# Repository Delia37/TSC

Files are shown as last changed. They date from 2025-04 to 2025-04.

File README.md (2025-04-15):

# EBookReader

Am inceput implementarea proiectului pornind de la schema electrica data in enunt. Am luat pe rand componentele din biblioteca pusa la dispozitie, apoi le-am conctat si le-am pus label-urile. Am verificat cu ERC si am rezolvat erorile, majoritatea fiind de la pini suprapusi sau etichete puse prost. Am ramas cu o eroare pe care nu am putut sa o rezolv, deoarece Fusion nu i-a detectat locatia. Odata terminata schema electrica, am facut trecut la implementarea pcb-ului. Am decupat forma dupa dimensiunile cerute si am masurat laturile. Dificultatea cea mai mare de la acest pas a constat in identificarea pieselor. Dupa amplasarea lor, am rutat si am verificat cu regulile date in enunt. Aici a fost nevoie sa modific footprint-ul bobinei L1 pentru a nu mai avea erori. La final, am facut si planul de masa atat pe top, cat si pe bottom.

---

## Arhitectură Generală a Sistemului

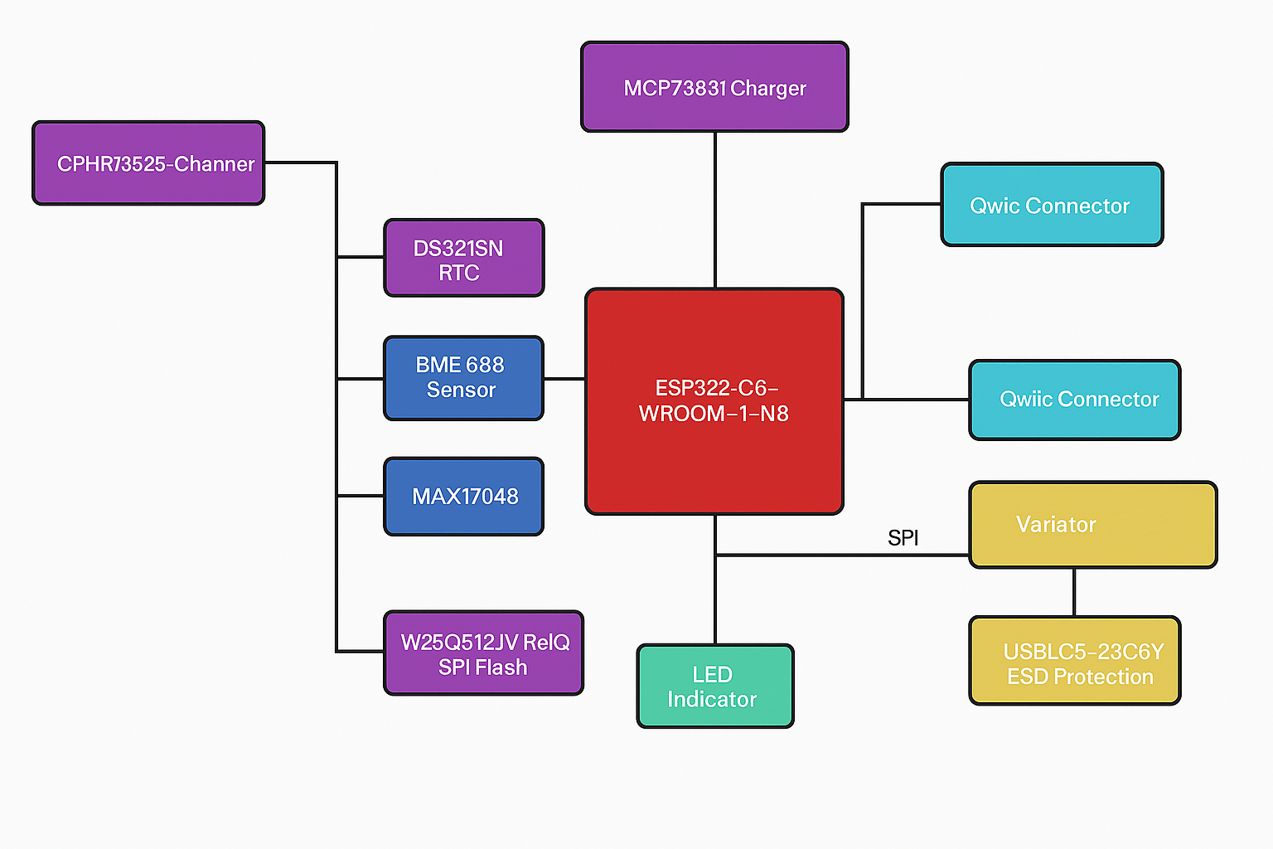
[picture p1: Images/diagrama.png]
Diagrama Bloc


ESP32-C6-WROOM-1-N8 acționează ca nod central, comunicând cu toate celelalte componente prin interfețe standard (I2C, SPI, GPIO). Alimentarea este asigurată de o baterie Li-Po controlată de un încărcător dedicat și monitorizată printr-un fuel gauge.

---

## Detalii Hardware

### ESP32-C6
- Procesor RISC-V cu conectivitate Wi-Fi 6 & BLE
- Comunicare: SPI, I2C, GPIO, UART
- Tensiune operare: 3.3V

### Management Energie
- MCP73831 – control încărcare baterie LiPo
- MAX17048 – monitorizare nivel baterie cu semnal alertă
- XC6220A331MR – stabilizare la 3.3V

### Senzori și RTC
- BME688 – monitorizare temperatură, umiditate, presiune, VOC (I2C)
- DS3231SN – ceas de timp real cu alarmă (I2C)

### Display și Stocare
- E-paper display – consum redus, ideal pentru afișaj static
- W25Q512JVEIQ – memorie NOR SPI externă, 64Mbit
- SD Card – opțional, conectat prin SPI partajat

### Protecție și Conectivitate
- Protecție ESD pe linii USB (USBLC6)
- Diode Schottky pentru protecție la supratensiune
- Port USB-C pentru alimentare și comunicație serială

### Interfețe Utilizator
- Buton RESET
- LED pentru starea încărcării

---

## Bill of Materials (CSV)

Fișierul complet BOM este disponibil aici: [Manufacturing/bom.csv](../Manufacturing/bom.csv)

---

## Alocare Pini ESP32-C6

| Componentă | Pin ESP32 | Funcție |
|---|---|---|
| BME688 – SDA | IO8 | I2C SDA |
| BME688 – SCL | IO9 | I2C SCL |
| DS3231SN – INT | IO10 | Interrupt RTC  |
| W25Q512 – CS | IO4 | SPI Flash CS |
| E-Paper – CS | IO3 | SPI Display CS |
| SPI – CLK | IO5 | SPI Clock |
| SPI – MOSI | IO6 | SPI MOSI |
| SPI – MISO | IO7 | SPI MISO |
| MAX17048 – ALERT | IO11 | Fuel Gauge INT |
| Buton RESET | IO0 | Boot/Reset |
| SD Card – CS | IO2 | SPI CS SD Card |

---
## Imagini Asamblare și PCB

### Randare 3D
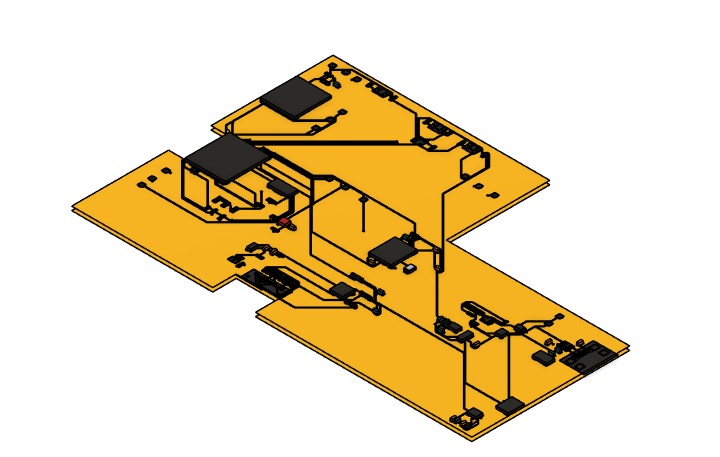
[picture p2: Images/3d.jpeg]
Randare 3D


### PCB - Top Layer
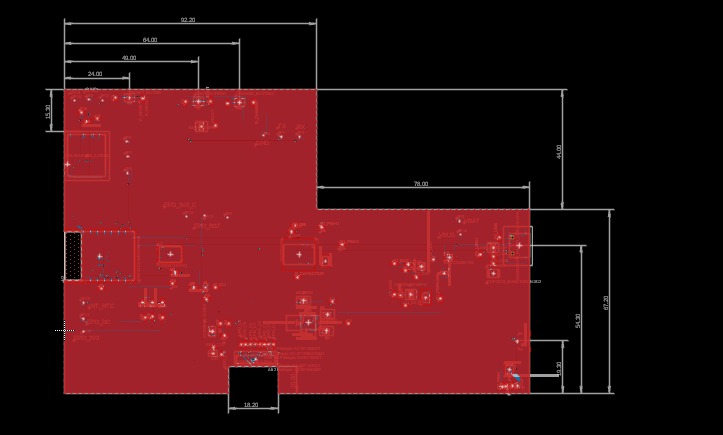
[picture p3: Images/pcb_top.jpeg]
PCB Top


### PCB - Bottom Layer
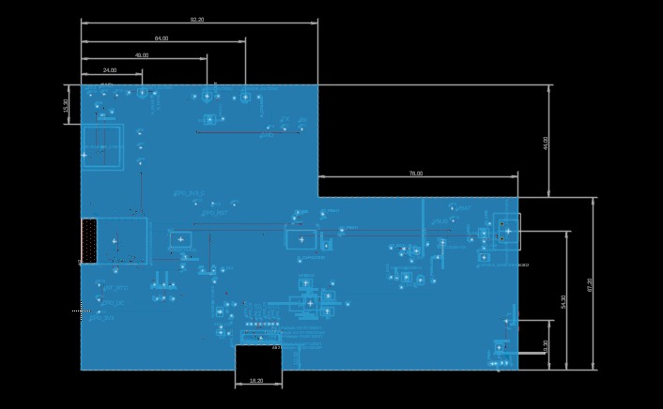
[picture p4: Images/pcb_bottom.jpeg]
PCB Bottom


---

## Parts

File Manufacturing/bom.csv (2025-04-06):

Qty | Value | Device | Package | Parts | Description | ARROW_PART_NUMBER | ARROW_PRICE-STOCK | AVAILABILITY | CENTROID_NOT_SPECIFIED | CHECK_PRICES | COPYRIGHT | DATASHEET | DESCRIPTION | DIGIKEY_DESCRIPTION | DIGIKEY_PART_NUMBER | HEIGHT | LEAD_FREE | MANUFACTURER_NAME | MANUFACTURER_PART_NUMBER | MF | MFR_NAME | MOUSER_PART_NUMBER | MOUSER_PRICE-STOCK | MOUSER_TESTING_PART_NUMBER | MOUSER_TESTING_PRICE-STOCK | MP | MPN | PACKAGE | POPULARITY | PREFIX | PRICE | PROD_ID | PURCHASE-URL | ROHS | SNAPEDA_LINK | SPICEMODEL | SPICEPREFIX | TEMPERATURE_RANGE_HIGH | TEMPERATURE_RANGE_LOW | TP_SIGNAL_NAME | VALUE
1 |  | ADAFRUIT_LEDCHIP-LED0603 | ADAFRUIT_CHIP-LED0603 | CHG_LED | LED
1 |  | SJ | SJ | SJ1 | SMD solder JUMPER |  |  |  |  |  |  |  |  |  |  |  |  |  |  |  |  |  |  |  |  |  |  |  | 3
8 | 0.1uF/50V | ESP32_WROVER_EAGLE-LTSPICE_CC0402 | ESP32_WROVER_EAGLE-LTSPICE_C0402 | EPD_C5, EPD_C6, EPD_C7, EPD_C8, EPD_C9, EPD_C10, EPD_C11, EPD_C12 | CAPACITOR, European symbol |  |  |  |  |  |  |  |  |  |  |  |  |  |  |  |  |  |  |  |  |  |  |  |  |  |  |  |  |  |  | NONE | C
1 | 0.47 | ESP32_WROVER_EAGLE-LTSPICE_RR0402 | ESP32_WROVER_EAGLE-LTSPICE_R0402 | R3 | RESISTOR, European symbol |  |  |  |  |  |  |  |  |  |  |  |  |  |  |  |  |  |  |  |  |  |  |  |  |  |  |  |  |  |  | NONE | R
1 | 100K | ESP32_WROVER_EAGLE-LTSPICE_RR0402 | ESP32_WROVER_EAGLE-LTSPICE_R0402 | R1_PWRUSB | RESISTOR, European symbol
6 | 100nF | ESP32_WROVER_EAGLE-LTSPICE_CC0402 | ESP32_WROVER_EAGLE-LTSPICE_C0402 | C1, C2, C4_USB, C7, C8, C_DELAY | CAPACITOR, European symbol |  |  |  |  |  |  |  |  |  |  |  |  |  |  |  |  |  |  |  |  |  |  |  |  |  |  |  |  |  |  | NONE | C
1 | 100uF TANT | RCL_CPOL-EUCT3528 | RCL_CT3528 | C11 | POLARIZED CAPACITOR, European symbol |  |  |  |  |  |  |  |  |  |  |  |  |  |  |  |  |  |  |  |  |  |  |  | 0 |  |  |  |  |  |  |  | C
13 | 10K | ESP32_WROVER_EAGLE-LTSPICE_RR0402 | ESP32_WROVER_EAGLE-LTSPICE_R0402 | R1_PINH, R1_PINH1, R2-PINH, R2-PINH1, R5, R6, R7, R8, R9, R10, R_BOOT, R_CHANGE, R_RESET | RESISTOR, European symbol
2 | 10k | ESP32_WROVER_EAGLE-LTSPICE_RR0402 | ESP32_WROVER_EAGLE-LTSPICE_R0402 | R1, R_CL1 | RESISTOR, European symbol
1 | 10k | ESP32_WROVER_EAGLE-LTSPICE_RR0402 | ESP32_WROVER_EAGLE-LTSPICE_R0402 | R4 | RESISTOR, European symbol |  |  |  |  |  |  |  |  |  |  |  |  |  |  |  |  |  |  |  |  |  |  |  |  |  |  |  |  |  |  | NONE | R
4 | 10uF | ESP32_WROVER_EAGLE-LTSPICE_CC0402 | ESP32_WROVER_EAGLE-LTSPICE_C0402 | C3, C5, C6, C10 | CAPACITOR, European symbol |  |  |  |  |  |  |  |  |  |  |  |  |  |  |  |  |  |  |  |  |  |  |  |  |  |  |  |  |  |  | NONE | C
1 | 112A-TAAR-R03_ATTEND | 112A-TAAR-R03_ATTEND | 112ATAARR03ATTEND | J4 | Micro SD Card Socket, Push-Push Type, Top Mount, SMT, H=1.83mm, 10u |  |  |  |  |  |  |  | Micro SD Card Socket | Push-Push Type | Top Mount | SMT | H=1.83mm | 10u |  |  | 1.9mm |  | ATTEND | 112A-TAAR-R03 ATTEND
1 | 15 | ESP32_WROVER_EAGLE-LTSPICE_RR0402 | ESP32_WROVER_EAGLE-LTSPICE_R0402 | R_CAPACITOR | RESISTOR, European symbol
2 | 1uF/50V | ESP32_WROVER_EAGLE-LTSPICE_CC0402 | ESP32_WROVER_EAGLE-LTSPICE_C0402 | EPD_C1, EPD_C2 | CAPACITOR, European symbol |  |  |  |  |  |  |  |  |  |  |  |  |  |  |  |  |  |  |  |  |  |  |  |  |  |  |  |  |  |  | NONE | C
1 | 2.2 | ESP32_WROVER_EAGLE-LTSPICE_RR0402 | ESP32_WROVER_EAGLE-LTSPICE_R0402 | R2 | RESISTOR, European symbol
1 | 200 | ESP32_WROVER_EAGLE-LTSPICE_RR0402 | ESP32_WROVER_EAGLE-LTSPICE_R0402 | R1_BAT | RESISTOR, European symbol
2 | 20V/4.2A/52mO/1.4W | ESP32_WROVER_SPARKFUN-DISCRETESEMI_MOSFET_PCH-DMG2305UX-7 | ESP32_WROVER_SPARKFUN-DISCRETESEMI_SOT23-3 | Q2, Q3 | P-channel MOSFETs |  |  |  |  |  |  |  |  |  |  |  |  |  |  |  |  |  |  |  |  |  |  |  |  |  |  | TRAN-14388 |  |  |  |  |  |  |  |  | 20V/4.2A/52mO/1.4W
1 | 2k | ESP32_WROVER_EAGLE-LTSPICE_RR0402 | ESP32_WROVER_EAGLE-LTSPICE_R0402 | R2_BAT | RESISTOR, European symbol
5 | 4.7uF | ESP32_WROVER_EAGLE-LTSPICE_CC0402 | ESP32_WROVER_EAGLE-LTSPICE_C0402 | C1_BAT, C1_BAT1, C1_BAT2, C2_BAT, C5_USB | CAPACITOR, European symbol |  |  |  |  |  |  |  |  |  |  |  |  |  |  |  |  |  |  |  |  |  |  |  |  |  |  |  |  |  |  | NONE | C
1 | 4.7uF/25V | ESP32_WROVER_EAGLE-LTSPICE_CC0402 | ESP32_WROVER_EAGLE-LTSPICE_C0402 | C4 | CAPACITOR, European symbol |  |  |  |  |  |  |  |  |  |  |  |  |  |  |  |  |  |  |  |  |  |  |  |  |  |  |  |  |  |  | NONE | C
1 | 5K1 | ESP32_WROVER_EAGLE-LTSPICE_RR0402 | ESP32_WROVER_EAGLE-LTSPICE_R0402 | R2-USB1 | RESISTOR, European symbol
1 | 5k1 | ESP32_WROVER_EAGLE-LTSPICE_RR0402 | ESP32_WROVER_EAGLE-LTSPICE_R0402 | R2-USB | RESISTOR, European symbol
1 | 68uH | 744043680IND_4828-WE-TPC_WRE | IND_4828-WE-TPC_WRE | L1 |  |  |  |  |  |  | Copyright (C) 2024 Ultra Librarian. All rights reserved. |  |  |  |  |  |  |  | 744043680 |  | Wurth Electronics
1 | BD5229G-TR | BD5229G-TR | SOT95P280X125-5N | IC1 | Voltage Detector with Adjustable Delay Time: CMOS processes are utilized to develop high precision, low current consumption CMOS reset ICs that allow arbitrary setting of the delay time. The extensive lineup includes both Nch Open Drain and CMOS output types in a wide range of detection voltages (from 2.3V to 6.0V, in 0.1V steps), enabling selection of the ideal solution based on customer requirements. In addition, the entire series is of course both lead-free and RoHS-compliant. |  |  |  |  |  |  |  | Voltage Detector with Adjustable Delay Time: CMOS processes are utilized to develop high precision | low current consumption CMOS reset ICs that allow arbitrary setting of the delay time. The extensive lineup includes both Nch Open Drain and CMOS output types in a wide range of detection voltages (from 2.3V to 6.0V | in 0.1V steps) | enabling selection of the ideal solution based on customer requirements. In addition | the entire series is of course both lead-free and RoHS-compliant. |  |  | 1.25mm |  | ROHM Semiconductor | BD5229G-TR |  |  | 755-BD5229G-TR | https://www.mouser.co.uk/ProductDetail/ROHM-Semiconductor/BD5229G-TR?qs=4kLU8WoGk0vvnhrrYwdszw%3D%3D
3 | BUTTON_CUSYOMV1 | BUTTON_CUSYOMV1 | MYBUTTON | BOOT_BUTTON, CHANGE_BUTTON, RESET_BUTTON
1 | CPH3225A | CPH3225A | CAPCP3225X100N | C10_SUPERCAP | Cap 0.011F 3.3V 1210 Flat Check availability |  |  | Not in stock |  | https://www.snapeda.com/parts/CPH3225A/Seiko+Instruments/view-part/?ref=eda |  |  | 11 mF (EDLC) Supercapacitor 3.3 V 1210 (3225 Metric) - - |  |  |  |  |  |  | Seiko Instruments |  |  |  |  |  | CPH3225A |  | 1210 Seiko |  |  | None |  | https://www.snapeda.com/api/url_track_click_mouser/?unipart_id=562593&manufacturer=Seiko Instruments&part_name=CPH3225A&search_term=None |  | https://www.snapeda.com/parts/CPH3225A/Seiko+Instruments/view-part/?ref=snap
1 | DS3231SN# | DS3231SN# | SOIC127P1032X265-16N | U3 | Real Time Clock Serial 16-Pin SOIC W T/R Check availability |  |  | In Stock |  | https://www.snapeda.com/parts/DS3231SN%23/Analog+Devices/view-part/?ref=eda |  |  | Extremely Accurate I²C-Integrated RTC/TCXO/Crystal |  |  |  |  |  |  | Analog Devices |  |  |  |  |  | DS3231SN# |  | SOIC-16 Maxim |  |  | None |  | https://www.snapeda.com/api/url_track_click_mouser/?unipart_id=99048&manufacturer=Analog Devices&part_name=DS3231SN#&search_term=None |  | https://www.snapeda.com/parts/DS3231SN%23/Analog+Devices/view-part/?ref=snap
1 | ESP32-C6-WROOM-1-N8 | ESP32-C6-WROOM-1-N8 | XCVR_ESP32-C6-WROOM-1-N8 | U2 | Check availability |  |  | In Stock |  | https://www.snapeda.com/parts/ESP32-C6-WROOM-1-N8/Espressif+Systems/view-part/?ref=eda |  |  | Multiprotocol Modules ESP32-C6 module | Wi-Fi 6 in 2.4 GHz band | Bluetooth 5 | Zigbee 3.0 and Thread. ESP34-WROOM Compatible - ENGINEERING SAMPLE |  |  |  |  |  |  | Espressif Systems |  |  |  |  |  | ESP32-C6-WROOM-1-N8 |  | None |  |  | None |  |  |  | https://www.snapeda.com/parts/ESP32-C6-WROOM-1-N8/Espressif+Systems/view-part/?ref=snap
1 | ESP32C6_VARISTORCN1812 | ESP32C6_VARISTORCN1812 | ESP32C6_VARISTOR_CT/CN1812 | PFMF.050.1 | VARISTOR |  |  |  |  |  |  |  |  |  |  |  |  |  |  |  |  |  |  |  |  |  |  |  | 0
2 | ESP32_WROVER_AVX---SD0805S020S1R0_AVX_SD0805S020S1R0_0_0AVX_SD0805S020S1R0_0_0 | ESP32_WROVER_AVX---SD0805S020S1R0_AVX_SD0805S020S1R0_0_0AVX_SD0805S020S1R0_0_0 | ESP32_WROVER_AVX---SD0805S020S1R0_AVX_SD0805S020S1R0_0 | D2, D7 | Schottky Barrier Rectifier Diode |  |  |  | No |  |  | http://datasheets.avx.com/schottky.pdf |  | DIODE SCHOTTKY 20V 1A 0805 | 478-7800-1-ND |  | yes |  |  | AVX |  | 581-SD0805S020S1R0 |  |  |  |  |  | 0805 (2012 metric) |  | D |  |  |  | yes |  |  |  | +125°C | -55°C
1 | ESP32_WROVER_BME680_BME680 | ESP32_WROVER_BME680_BME680 | ESP32_WROVER_BME680_PSON80P300X300X100-8N | SENSOR2 | Integrated Environmental Unit |  |  | Unavailable |  |  |  |  | Integrated Environmental Unit |  |  |  |  |  |  | Bosch Sensortec |  |  |  |  |  | BME680 |  | LGA-8 Bosch Tools |  |  | None
1 | ESP32_WROVER_SPARKFUN-IC-POWER_MCP73831 | ESP32_WROVER_SPARKFUN-IC-POWER_MCP73831 | ESP32_WROVER_SPARKFUN-IC-POWER_SOT23-5 | MCP73831 | MCP73831T Li-Ion, Li-Pol Controller |  |  |  |  |  |  |  |  |  |  |  |  |  |  |  |  |  |  |  |  |  |  |  |  |  |  | IC-09995
1 | FH34SRJ-24S-0.5SH_99_ | FH34SRJ-24S-0.5SH_99_ | FH34SRJ24S05SH99 | J1 | (0.50mm) Surface Mount, Right Angle |  |  |  |  |  |  |  | 24 Position FFC | FPC Connector Contacts | (0.50mm) Surface Mount | Right Angle |  |  | 1.1mm |  | Hirose | FH34SRJ-24S-0.5SH(99) |  |  | 798-FH34SRJ24S05SH99 | https://www.mouser.co.uk/ProductDetail/Hirose-Connector/FH34SRJ-24S-0.5SH99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
1 | MAX17048G+T10 | MAX17048G+T10 | SON50P200X200X80-9N | U4 | Check availability |  |  | In Stock |  | https://www.snapeda.com/parts/MAX17048G+T10/Analog+Devices/view-part/?ref=eda |  |  | 3µA 1-Cell/2-Cell Fuel Gauge with ModelGauge |  |  |  |  |  |  | Analog Devices |  |  |  |  |  | MAX17048G+T10 |  | TDFN-8 Maxim |  |  | None |  | https://www.snapeda.com/api/url_track_click_mouser/?unipart_id=329239&manufacturer=Analog Devices&part_name=MAX17048G+T10&search_term=None |  | https://www.snapeda.com/parts/MAX17048G+T10/Analog+Devices/view-part/?ref=snap
3 | MBR0530 | MBR0530 | SOD3716X135N | D3, D4, D5 | ON SEMICONDUCTOR - MBR0530 - DIODE, SCHOTTKY, 0.5A, 30V, SOD-123 |  |  | In Stock |  | https://www.snapeda.com/parts/MBR0530/Onsemi/view-part/?ref=eda |  |  | Diode Schottky 30 V 500mA Surface Mount SOD-123 |  |  |  |  |  |  | ON Semiconductor |  |  |  |  |  | MBR0530 |  | SOD-123-2 ON Semiconductor |  |  | None |  | https://www.snapeda.com/api/url_track_click_mouser/?unipart_id=179458&manufacturer=ON Semiconductor&part_name=MBR0530&search_term=None |  | https://www.snapeda.com/parts/MBR0530/Onsemi/view-part/?ref=snap
6 | PGB1010603MR | PGB1010603MR | DIOC1608X36N | D6, D8, D9, D10, D11, D12 | Check availability |  |  | In Stock |  | https://www.snapeda.com/parts/PGB1010603MR/Littelfuse/view-part/?ref=eda |  |  | 150V (Typ) Clamp - Ipp Tvs Diode Surface Mount 0603 (1608 Metric) |  |  |  |  |  |  | Littelfuse Inc. |  |  |  |  |  | PGB1010603MR |  | 0603 Littelfuse Inc. |  |  | None |  | https://www.snapeda.com/api/url_track_click_mouser/?unipart_id=5659453&manufacturer=Littelfuse Inc.&part_name=PGB1010603MR&search_term=None |  | https://www.snapeda.com/parts/PGB1010603MR/Littelfuse/view-part/?ref=snap
1 | QWIIC_RIGHT_ANGLE | QWIIC_CONNECTORJS-1MM | JST04_1MM_RA | J3 | SparkFun I2C Standard Qwiic Connector |  |  |  |  |  |  |  |  |  |  |  |  |  |  |  |  |  |  |  |  |  |  |  |  |  |  | CONN-13694 |  |  |  |  |  |  |  |  | QWIIC_RIGHT_ANGLE
1 | SAMACSYS_PARTS_USB4110-GF-A | SAMACSYS_PARTS_USB4110-GF-A | SAMACSYS_PARTS_USB4110GFA | J2 | CONN USB 2.0 TYPE-C R/A SMT |  |  |  |  |  |  |  | CONN USB 2.0 TYPE-C R/A SMT |  |  | 3.26mm |  | GCT (GLOBAL CONNECTOR TECHNOLOGY) | USB4110-GF-A |  |  | 640-USB4110-GF-A | https://www.mouser.co.uk/ProductDetail/GCT/USB4110-GF-A?qs=KUoIvG%2F9IlYiZvIXQjyJeA%3D%3D
1 | SI1308EDL-T1-GE3 | SI1308EDL-T1-GE3 | SOT65P210X110-3N | Q1 | MOSFET N-Ch 30V 1.5A TrenchFET SC70 Vishay Si1308EDL-T1-GE3 N-channel MOSFET Transistor, 1.5 A, 30 V, 3-Pin SC-70 |  |  | In Stock |  | https://www.snapeda.com/parts/SI1308EDL-T1-GE3/Vishay+Siliconix/view-part/?ref=eda |  |  | Si1308EDL-T1-GE3 N-channel MOSFET Transistor | 1.5 A | 30 V | 3-Pin SC-70 | Siliconix / Vishay SI1308EDL-T1-GE3 |  |  |  |  |  |  | Vishay Siliconix |  |  |  |  |  | SI1308EDL-T1-GE3 |  | SOT-323 Vishay Semiconductor |  |  | None |  | https://www.snapeda.com/api/url_track_click_mouser/?unipart_id=274603&manufacturer=Vishay Siliconix&part_name=SI1308EDL-T1-GE3&search_term=None |  | https://www.snapeda.com/parts/SI1308EDL-T1-GE3/Vishay+Siliconix/view-part/?ref=snap
17 | TPTP20R | TPTP20R | TP20R | TP1, TP2, TP3, TP4, TP5, TP6, TP7, TP8, TP9, TP10, TP11, TP12, TP13, TP14, TP15, TP16, TP17 | Test pad |  |  |  |  |  |  |  |  |  |  |  |  |  |  |  |  |  |  |  |  |  |  |  | 2
1 | USBLC6-2SC6Y | USBLC6-2SC6Y | SOT95P280X145-6N | D1 | Low Cap. ESD Protection Auto SOT-23-6 STMicroelectronics USBLC6-2SC6Y, Dual Uni-Directional TVS Diode Array, 6-Pin SOT-23 |  |  | In Stock |  | https://www.snapeda.com/parts/USBLC6-2SC6Y/STMicroelectronics/view-part/?ref=eda |  |  | 17V Clamp 5A (8/20µs) Ipp Tvs Diode Surface Mount SOT-23-6 |  |  |  |  |  |  | STMicroelectronics |  |  |  |  |  | USBLC6-2SC6Y |  | SOT-23-6 STMicroelectronics |  |  | None |  |  |  | https://www.snapeda.com/parts/USBLC6-2SC6Y/STMicroelectronics/view-part/?ref=snap
1 | W25Q512JVEIQ | W25Q512JVEIQ | SON127P600X800X80-9N | U1 | Check availability |  |  | In Stock |  | https://www.snapeda.com/parts/W25Q512JVEIQ/Winbond+Electronics/view-part/?ref=eda |  |  | FLASH - NOR Memory IC 512Mb (64M x 8) SPI - Quad I/O 133 MHz 8-WSON (8x6) |  |  |  |  |  |  | Winbond Electronics |  |  |  |  |  | W25Q512JVEIQ |  | Package |  |  | None |  |  |  | https://www.snapeda.com/parts/W25Q512JVEIQ/Winbond+Electronics/view-part/?ref=snap
1 | XC6220A331MR-G | XC6220A331MR-G | SOT95P280X120-5N | IC2 | LDO Voltage Regulators |  |  |  |  |  |  |  | LDO Voltage Regulators |  |  | 1.2mm |  | Torex | XC6220A331MR-G |  |  | 865-XC6220A331MR-G | https://www.mouser.co.uk/ProductDetail/Torex-Semiconductor/XC6220A331MR-G?qs=AsjdqWjXhJ8ZSWznL1J0gg%3D%3D

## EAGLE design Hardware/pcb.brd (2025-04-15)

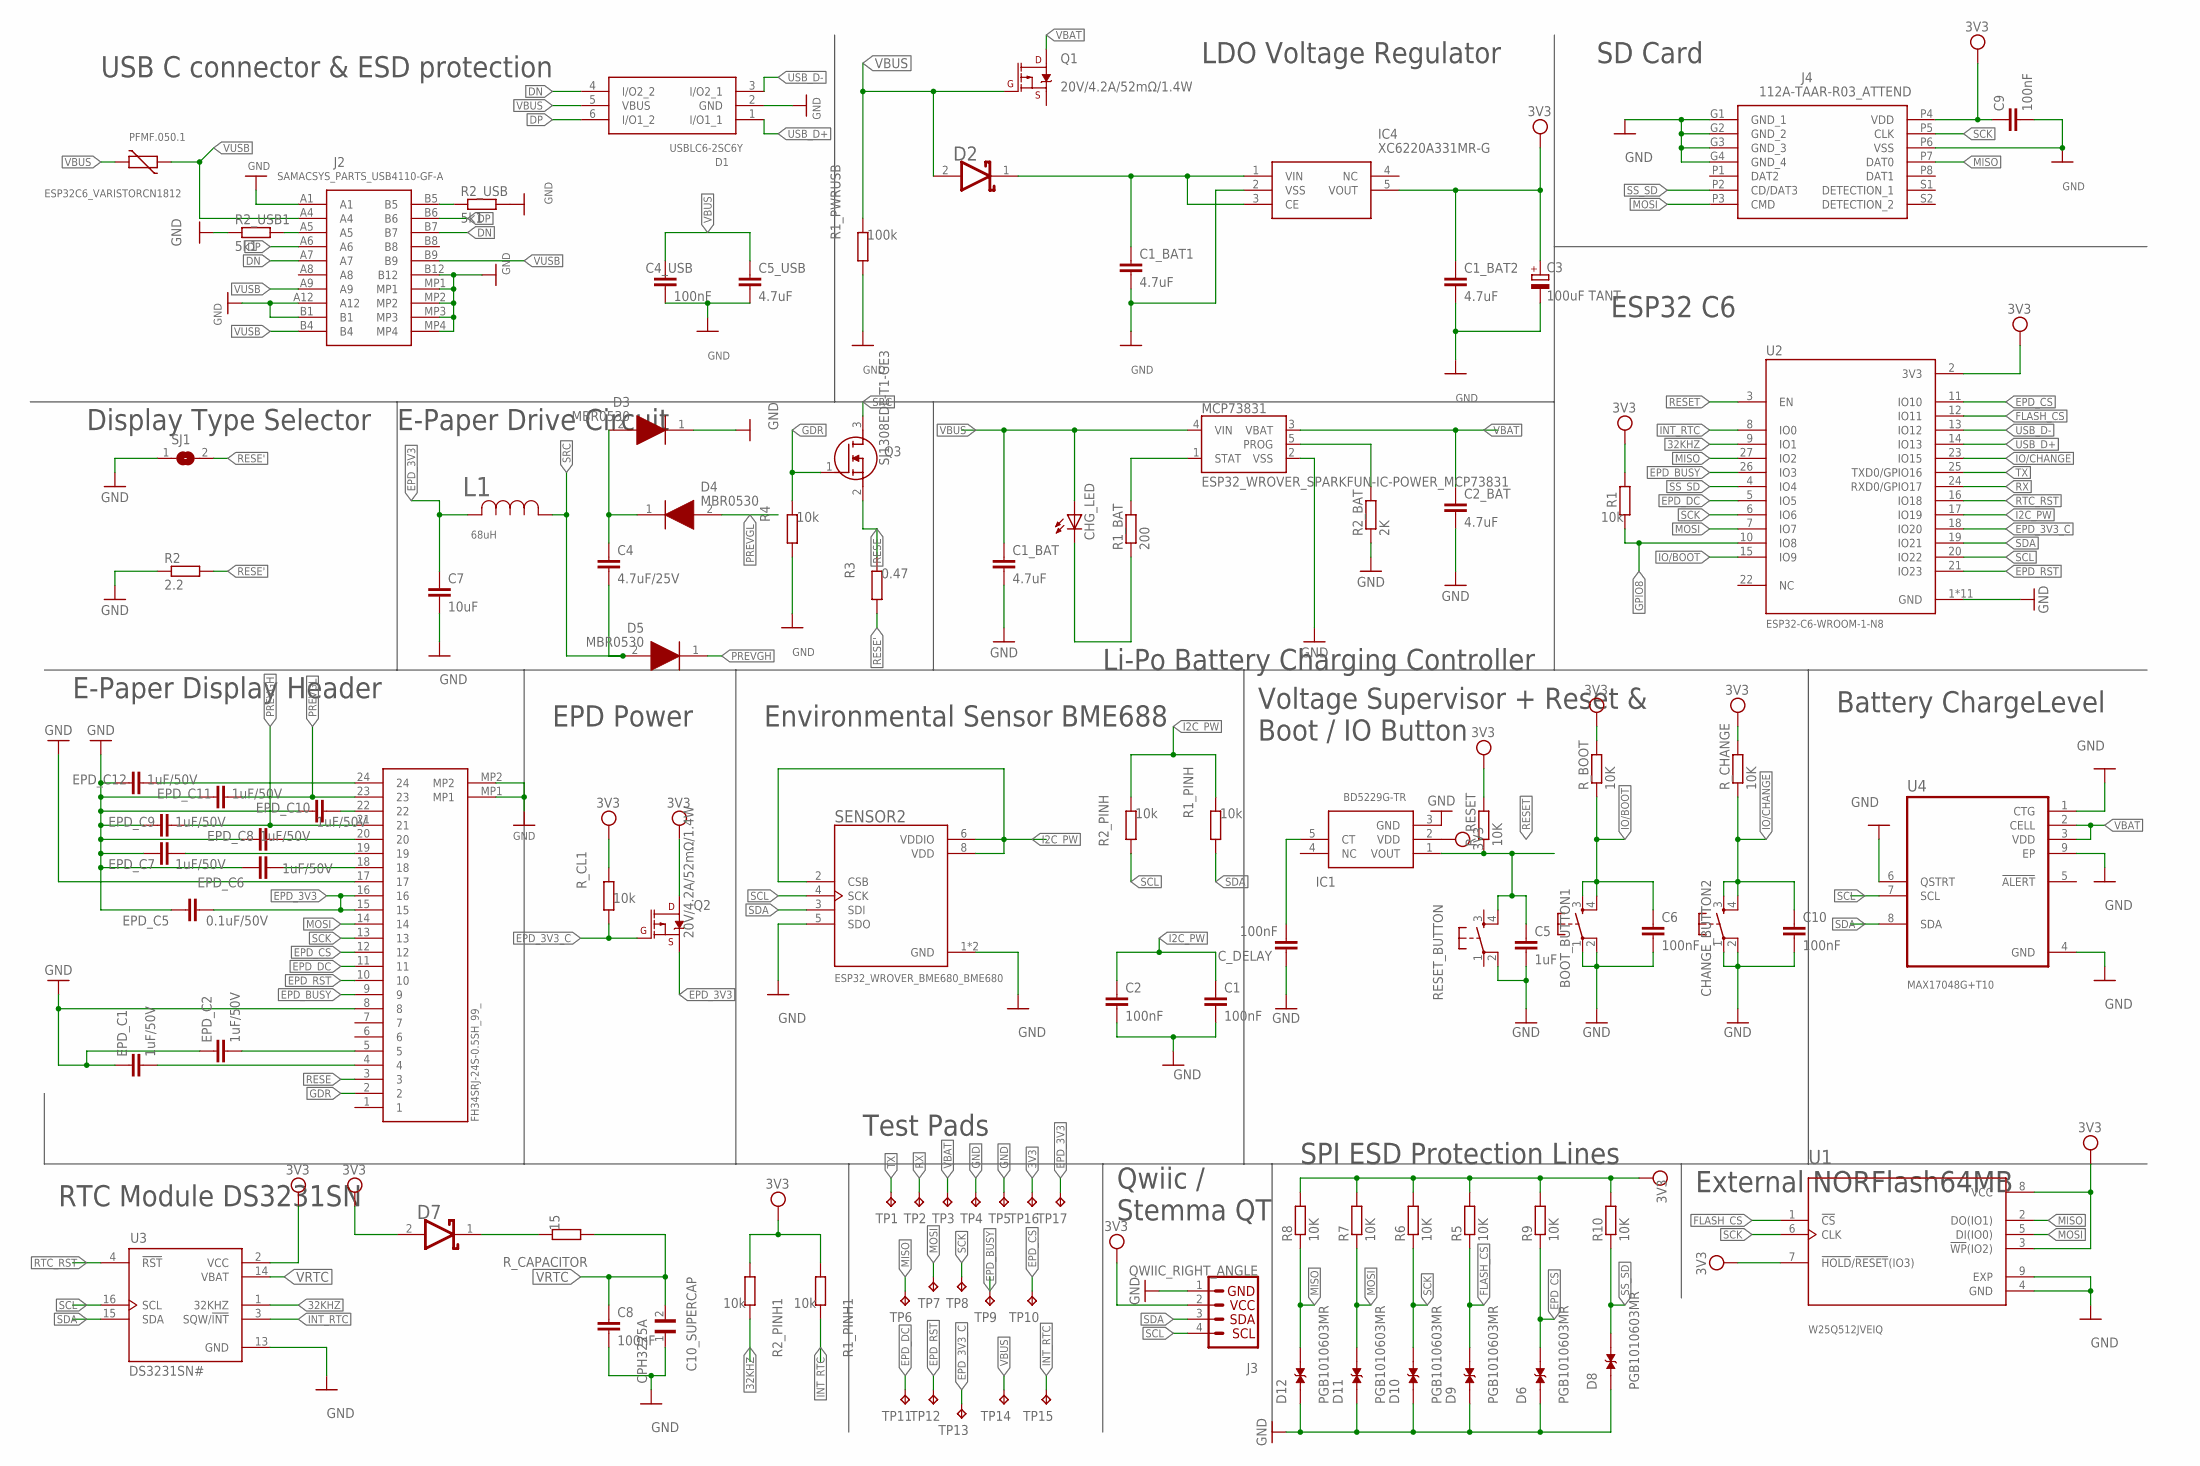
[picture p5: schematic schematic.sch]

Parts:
BOOT_BUTTON1: BUTTON_CUSYOMV1; MYBUTTON
C1, C2, C4_USB, C6, C8, C9, C10: 100nF; EAGLE-LTSPICE_C0402
C1_BAT, C1_BAT1, C1_BAT2, C2_BAT, C5_USB: 4.7uF; EAGLE-LTSPICE_C0402
C3: 100uF TANT; RCL_CT3528
C4: 4.7uF/25V; EAGLE-LTSPICE_C0402
C5: 1uF; EAGLE-LTSPICE_C0402
C7: 10uF; EAGLE-LTSPICE_C0402
C10_SUPERCAP: CPH3225A; CAPCP3225X100N
CHANGE_BUTTON2: BUTTON_CUSYOMV1; MYBUTTON
CHG_LED: ADAFRUIT_LEDCHIP-LED0603; ADAFRUIT_CHIP-LED0603
C_DELAY: 100nF; EAGLE-LTSPICE_C0402
D1: USBLC6-2SC6Y; SOT95P280X145-6N
D2, D7: ESP32_WROVER_AVX---SD0805S020S1R0_AVX_SD0805S020S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; ESP32_WROVER_AVX---SD0805S020S1R0_AVX_SD0805S020S1R0_0
D3, D4, D5: MBR0530; SOD3716X135N
D6, D8, D9, D10, D11, D12: PGB1010603MR; DIOC1608X36N
EPD_C1, EPD_C2, EPD_C6, EPD_C7, EPD_C8, EPD_C9, EPD_C10, EPD_C11, EPD_C12: 1uF/50V; EAGLE-LTSPICE_C0402
EPD_C5: 0.1uF/50V; EAGLE-LTSPICE_C0402
FH34SRJ-24S-0.5SH_99_: FH34SRJ-24S-0.5SH_99_; FH34SRJ24S05SH99
IC1: BD5229G-TR; SOT95P280X125-5N
IC4: XC6220A331MR-G; SOT95P280X120-5N
J2: SAMACSYS_PARTS_USB4110-GF-A; SAMACSYS_PARTS_USB4110GFA
J3: QWIIC_RIGHT_ANGLE; JST04_1MM_RA
J4: 112A-TAAR-R03_ATTEND; 112ATAARR03ATTEND
L1: 68uH; IND_4828-WE-TPC_WRE
MCP73831: ESP32_WROVER_SPARKFUN-IC-POWER_MCP73831; ESP32_WROVER_SPARKFUN-IC-POWER_SOT23-5
PFMF.050.1: ESP32C6_VARISTORCN1812; ESP32C6_VARISTOR_CT/CN1812
Q1, Q2: 20V/4.2A/52mΩ/1.4W; ESP32_WROVER_SPARKFUN-DISCRETESEMI_SOT23-3
Q3: SI1308EDL-T1-GE3; SOT65P210X110-3N
R1, R1_PINH, R1_PINH1, R2_PINH, R2_PINH1, R4: 10k; ESP32_WROVER_EAGLE-LTSPICE_R0402
R1_BAT: 200; ESP32_WROVER_EAGLE-LTSPICE_R0402
R1_PWRUSB: 100k; ESP32_WROVER_EAGLE-LTSPICE_R0402
R2: 2.2; ESP32_WROVER_EAGLE-LTSPICE_R0402
R2_BAT: 2K; ESP32_WROVER_EAGLE-LTSPICE_R0402
R2_USB, R2_USB1: 5k1; ESP32_WROVER_EAGLE-LTSPICE_R0402
R3: 0.47; ESP32_WROVER_EAGLE-LTSPICE_R0402
R5, R6, R7, R8, R9, R10: 10K; ESP32_WROVER_EAGLE-LTSPICE_R0402
RESET_BUTTON: BUTTON_CUSYOMV1; MYBUTTON
R_BOOT: 10K; ESP32_WROVER_EAGLE-LTSPICE_R0402
R_CAPACITOR: 15; ESP32_WROVER_EAGLE-LTSPICE_R0402
R_CHANGE: 10K; ESP32_WROVER_EAGLE-LTSPICE_R0402
R_CL1: 10k; ESP32_WROVER_EAGLE-LTSPICE_R0402
R_RESET: 10K; ESP32_WROVER_EAGLE-LTSPICE_R0402
SENSOR2: ESP32_WROVER_BME680_BME680; ESP32_WROVER_BME680_PSON80P300X300X100-8N
SJ1: SJ
TP1, TP2, TP3, TP4, TP5, TP6, TP7, TP8, TP9, TP10, TP11, TP12, TP13, TP14, TP15, TP16, TP17: TPTP20R; TP20R
U1: W25Q512JVEIQ; SON127P600X800X80-9N
U2: ESP32-C6-WROOM-1-N8; XCVR_ESP32-C6-WROOM-1-N8
U3: DS3231SN#; SOIC127P1032X265-16N
U4: MAX17048G+T10; SON50P200X200X80-9N

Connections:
3V3: C1_BAT2.1, C3.+, C9.1, D7.2 (ANODE), IC1.2 (VDD), IC4.5 (VOUT), J3.2, J4.P4 (VDD), Q2.3 (D), R1.2, R1_PINH1.1, R2_PINH1.1, R5.2, R6.2, R7.2, R8.2, R9.2, R10.2, R_BOOT.2, R_CHANGE.2, R_CL1.2, R_RESET.2, TP16.TP, U1.3 (!WP!(IO2)), U1.7 (!HOLD!/!RESET!(IO3)), U1.8 (VCC), U2.2 (3V3), U3.2 (VCC)
32KHZ: R2_PINH1.2, U2.9 (IO1), U3.1 (32KHZ)
DN: D1.4 (I/O2_2), J2.A7, J2.B7
DP: D1.6 (I/O1_2), J2.A6, J2.B6
EPD_3V3: C7.1, EPD_C5.2, FH34SRJ-24S-0.5SH_99_.15, FH34SRJ-24S-0.5SH_99_.16, L1.2, Q2.2 (S), TP17.TP
EPD_3V3_C: Q2.1 (G), R_CL1.1, TP13.TP, U2.18 (IO20)
EPD_BUSY: FH34SRJ-24S-0.5SH_99_.9, TP9.TP, U2.26 (IO3)
EPD_CS: D6.2, FH34SRJ-24S-0.5SH_99_.12, R9.1, TP10.TP, U2.11 (IO10)
EPD_DC: FH34SRJ-24S-0.5SH_99_.11, TP11.TP, U2.5 (IO5)
EPD_RST: FH34SRJ-24S-0.5SH_99_.10, TP12.TP, U2.21 (IO23)
FLASH_CS: D9.2, R5.1, U1.1 (!CS), U2.12 (IO11)
GDR: FH34SRJ-24S-0.5SH_99_.2, Q3.1 (G), R4.2
GND: BOOT_BUTTON1.1, BOOT_BUTTON1.2, C1.2, C1_BAT.2, C1_BAT1.2, C1_BAT2.2, C2.2, C2_BAT.2, C3.-, C4_USB.2, C5.2, C5_USB.2, C6.2, C7.2, C8.2, C9.2, C10.2, C10_SUPERCAP.1, CHANGE_BUTTON2.1, CHANGE_BUTTON2.2, C_DELAY.1, D1.2 (GND), D3.1 (K), D6.1, D8.1, D9.1, D10.1, D11.1, D12.1, EPD_C1.1, EPD_C2.1, EPD_C5.1, EPD_C6.1, EPD_C7.1, EPD_C8.1, EPD_C9.1, EPD_C10.1, EPD_C11.1, EPD_C12.1, FH34SRJ-24S-0.5SH_99_.8, FH34SRJ-24S-0.5SH_99_.17, FH34SRJ-24S-0.5SH_99_.MP1, FH34SRJ-24S-0.5SH_99_.MP2, IC1.3 (GND), IC4.2 (VSS), J2.A1, J2.A12, J2.B1, J2.B12, J2.MP1, J2.MP2, J2.MP3, J2.MP4, J3.1, J4.G1 (GND_1), J4.G2 (GND_2), J4.G3 (GND_3), J4.G4 (GND_4), J4.P6 (VSS), MCP73831.2 (VSS), R1_PWRUSB.1, R2.1, R2_BAT.1, R2_USB.2, R2_USB1.1, R4.1, RESET_BUTTON.2, SENSOR2.1 (GND), SENSOR2.5 (SDO), SENSOR2.7 (GND), SJ1.1, TP4.TP, TP5.TP, U1.4 (GND), U1.9 (EXP), U2.1 (GND), U2.28 (GND), U2.29_1 (GND), U2.29_2 (GND), U2.29_3 (GND), U2.29_4 (GND), U2.29_5 (GND), U2.29_6 (GND), U2.29_7 (GND), U2.29_8 (GND), U2.29_9 (GND), U3.13 (GND), U4.1 (CTG), U4.4 (GND), U4.6 (QSTRT), U4.9 (EP)
GPIO8: R1.1, U2.10 (IO8)
I2C_PW: C1.1, C2.1, R1_PINH.2, R2_PINH.2, SENSOR2.2 (CSB), SENSOR2.6 (VDDIO), SENSOR2.8 (VDD), U2.17 (IO19)
INT_RTC: R1_PINH1.2, TP15.TP, U2.8 (IO0), U3.3 (SQW/!INT)
IO/BOOT: BOOT_BUTTON1.3, BOOT_BUTTON1.4, C6.1, R_BOOT.1, U2.15 (IO9)
IO/CHANGE: C10.1, CHANGE_BUTTON2.3, CHANGE_BUTTON2.4, R_CHANGE.1, U2.23 (IO15)
MISO: D12.2, J4.P7 (DAT0), R8.1, TP6.TP, U1.2 (DO(IO1)), U2.27 (IO2)
MOSI: D11.2, FH34SRJ-24S-0.5SH_99_.14, J4.P3 (CMD), R7.1, TP7.TP, U1.5 (DI(IO0)), U2.7 (IO7)
unnamed: J2.A5, R2_USB1.2
unnamed: J2.B5, R2_USB.1
unnamed: D7.1 (CATHODE), R_CAPACITOR.2
unnamed: MCP73831.1 (STAT), R1_BAT.2
unnamed: C4.1, D3.2 (A), D4.1 (K)
unnamed: CHG_LED.C, R1_BAT.1
unnamed: MCP73831.5 (PROG), R2_BAT.2
unnamed: EPD_C12.2, FH34SRJ-24S-0.5SH_99_.24
unnamed: EPD_C8.2, FH34SRJ-24S-0.5SH_99_.20
unnamed: EPD_C10.2, FH34SRJ-24S-0.5SH_99_.22
unnamed: EPD_C7.2, FH34SRJ-24S-0.5SH_99_.19
unnamed: EPD_C6.2, FH34SRJ-24S-0.5SH_99_.18
unnamed: EPD_C2.2, FH34SRJ-24S-0.5SH_99_.5
unnamed: EPD_C1.2, FH34SRJ-24S-0.5SH_99_.4
unnamed: C_DELAY.2, IC1.5 (CT)
unnamed: C1_BAT1.1, D2.1 (CATHODE), IC4.1 (VIN), IC4.3 (CE)
PREVGH: D5.1 (K), EPD_C9.2, FH34SRJ-24S-0.5SH_99_.21
PREVGL: D4.2 (A), EPD_C11.2, FH34SRJ-24S-0.5SH_99_.23
RESE: FH34SRJ-24S-0.5SH_99_.3, Q3.2 (S), R3.2
RESE': R2.2, R3.1, SJ1.2
RESET: C5.1, IC1.1 (VOUT), RESET_BUTTON.4, R_RESET.1, U2.3 (EN)
RTC_RST: U2.16 (IO18), U3.4 (!RST)
RX: TP2.TP, U2.24 (RXD0/GPIO17)
SCK: D10.2, FH34SRJ-24S-0.5SH_99_.13, J4.P5 (CLK), R6.1, TP8.TP, U1.6 (CLK), U2.6 (IO6)
SCL: J3.4, R2_PINH.1, SENSOR2.4 (SCK), U2.20 (IO22), U3.16 (SCL), U4.7 (SCL)
SDA: J3.3, R1_PINH.1, SENSOR2.3 (SDI), U2.19 (IO21), U3.15 (SDA), U4.8 (SDA)
SRC: C4.2, D5.2 (A), L1.1, Q3.3 (D)
SS_SD: D8.2, J4.P2 (CD/DAT3), R10.1, U2.4 (IO4)
TX: TP1.TP, U2.25 (TXD0/GPIO16)
USB_D+: D1.1 (I/O1_1), U2.14 (IO13)
USB_D-: D1.3 (I/O2_1), U2.13 (IO12)
VBAT: C2_BAT.1, MCP73831.3 (VBAT), Q1.3 (D), TP3.TP, U4.2 (CELL), U4.3 (VDD)
VBUS: C1_BAT.1, C4_USB.1, C5_USB.1, CHG_LED.A, D1.5 (VBUS), D2.2 (ANODE), MCP73831.4 (VIN), PFMF.050.1.2, Q1.1 (G), R1_PWRUSB.2, TP14.TP
VRTC: C8.1, C10_SUPERCAP.2, R_CAPACITOR.1, U3.14 (VBAT)
VUSB: J2.A4, J2.A9, J2.B4, J2.B9, PFMF.050.1.1

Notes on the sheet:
USB C connector & ESD protection
LDO Voltage Regulator
SD Card
Display Type Selector
E-Paper Drive Circuit
Li-Po Battery Charging Controller
ESP32 C6
E-Paper Display Header
EPD Power
Environmental Sensor BME688
Voltage Supervisor + Reset & Boot / IO Button
Battery ChargeLevel
RTC Module DS3231SN
Test Pads
Qwiic / Stemma QT
SPI ESD Protection Lines
External NORFlash64MB

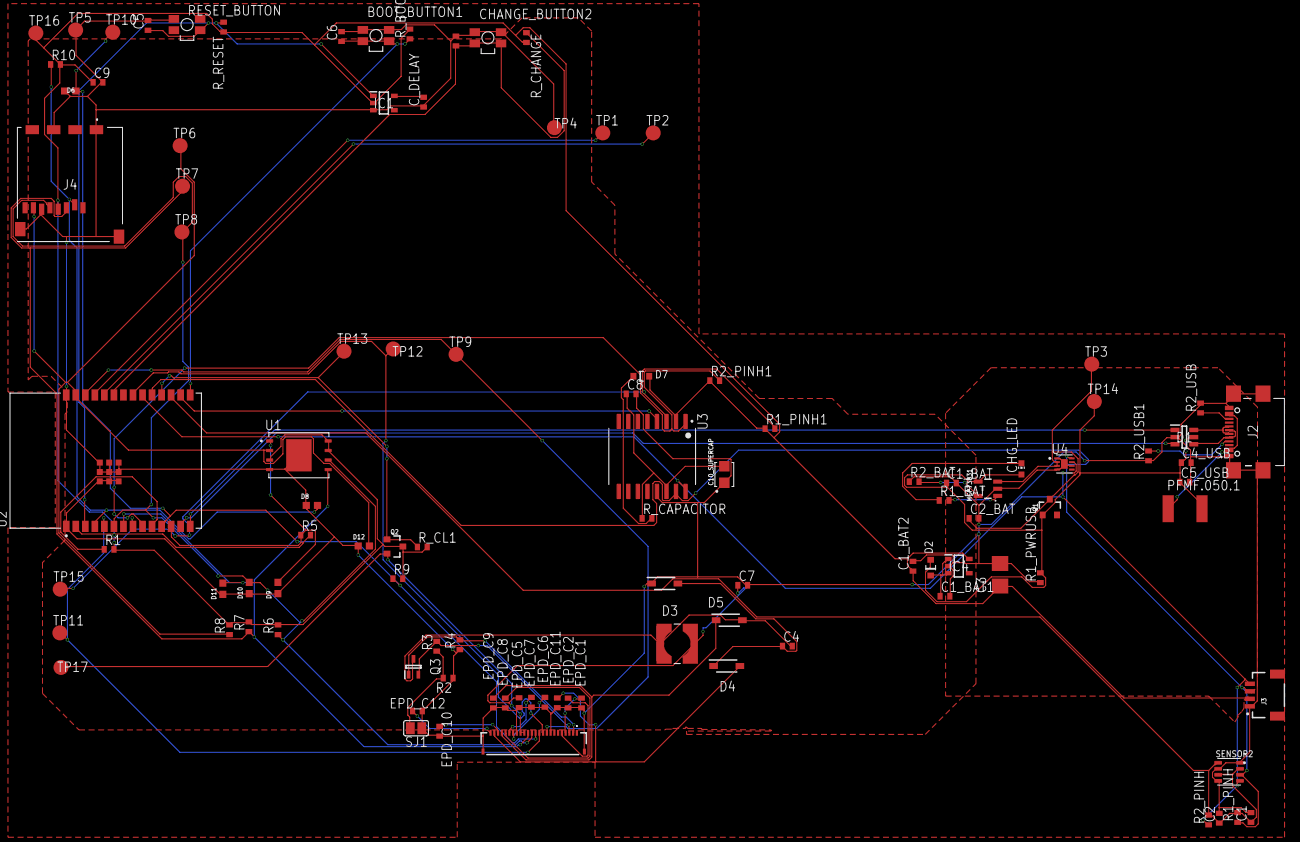
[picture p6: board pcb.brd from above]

Board: 2 copper layers, 103 parts (0 on the bottom side), 55 nets.

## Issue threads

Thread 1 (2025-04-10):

Denumiri incorecte la label-urilor și pini greșit conectați în Schematic

alexavoicu, 2025-04-10:
În urma comparării schemei electrice propuse cu cea din acest proiect am sesizat că aceasta conține probleme legate de denumiri incorecte ale label-urilor, conexiuni greșite între label-uri și pinii fizici ai componentelor și pini conectați greșit.

- [ ] Verificare alocare pini USB C connector & ESD protection
- [ ] Revizuire conexiuni Reset & Boot / IO Button
- [ ] Corectare label lipsă E-Paper Display Header
- [ ] Conexiuni și etichete corecte pentru LDO-Voltage Regulator

Closed 2025-04-15.

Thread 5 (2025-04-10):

Fișier README incomplet

alexavoicu, 2025-04-10:
În urma analizei am observat ca din fișierul README lipsește Bill Of Materials sub formă de tabel cu componentele sau modulele folosite și link-uri către locul de unde se pot procura și link către datasheet-ul lor.

Closed 2025-04-15.

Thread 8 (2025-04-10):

Revizuire layout PCB – probleme de poziționare, rutare și silkscreen

alexavoicu, 2025-04-10:
În urma unei evaluări a layout-ului PCB pentru acest proiect, au fost identificate mai multe probleme ce necesită corectare pentru a asigura funcționalitatea corectă și integrabilitatea în carcasă.
USB-C: Conectorul USB-C este prea în stânga, ceea ce creează un spațiu între mufă și marginea carcasei, deci nu ar putea fi realizată conectarea firului.
Qwiic right angle (J3) : pad-urile sunt prea departe, ceea ce lasă un spațiu între mufă și alinierea acestei pe carcasă ceea ce duce la a nu putea fi utilizată.
Nu există via stitching între cele două planuri de masă, în special în preajma modulului ESP32, pentru o împământare uniformă.
Planul de masă pe Top si Bottom este întrerupt, unele porțiuni nu sunt conectate la GND.
Silkscreen-ul conține și valorile componentelor, iar test pad-urile nu sunt clar marcate în silkscreen cu numele semnalelor pe care le poartă.

- [ ] Corectare poziție componente USB și Qwiic în raport cu marginea carcasei
- [ ] Aplicare via stitching
- [ ] Refacere plan de masă atât pe Top cât și pe bottom
- [ ] Corectare layer silkscreen trebuie astfel încât să fie citeț și să respecte cerințele

Closed 2025-04-15.

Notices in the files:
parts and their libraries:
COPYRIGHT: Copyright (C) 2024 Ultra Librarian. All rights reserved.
